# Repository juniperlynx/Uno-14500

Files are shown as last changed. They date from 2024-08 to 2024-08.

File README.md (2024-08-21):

# Uno 14500

The Uno 14500 is a demonstration and training system built around the Motorola MC14500BCP Industrial Control Unit.

Its design borrows heavily from several sources including the Motorola ICU Handbook, Usagi Electric's MC14500 SBC, Nicola Cimmino's PLC14500, and my original Uno computer, a CMOS CPU I wire wrapped in college.

The system has 256 bytes of program memory, an 8 bit scratch register, an 8 bit output register, and an 8 bit input mux.

Program Input is primarily through toggle switches on the front panel, though memory boards with external ROMs are planned for the future. Switch and LED I/O is built into the console, and an external I/O connector is provided to use other peripherals.

I/O and memory mapping is designed to be compatible with either the MCU demonstration system from the Motorola ICU Handbook and the PLC14500 and the mapping of RR into I/O space is jumper selectable on the "Config" header. This header also houses jumpers to enable usage of the JMP and F flags from the CPU for returning to the reset vector and halting the system respectively

This repo, and the system, are still very much works in progress so check back as things are added.

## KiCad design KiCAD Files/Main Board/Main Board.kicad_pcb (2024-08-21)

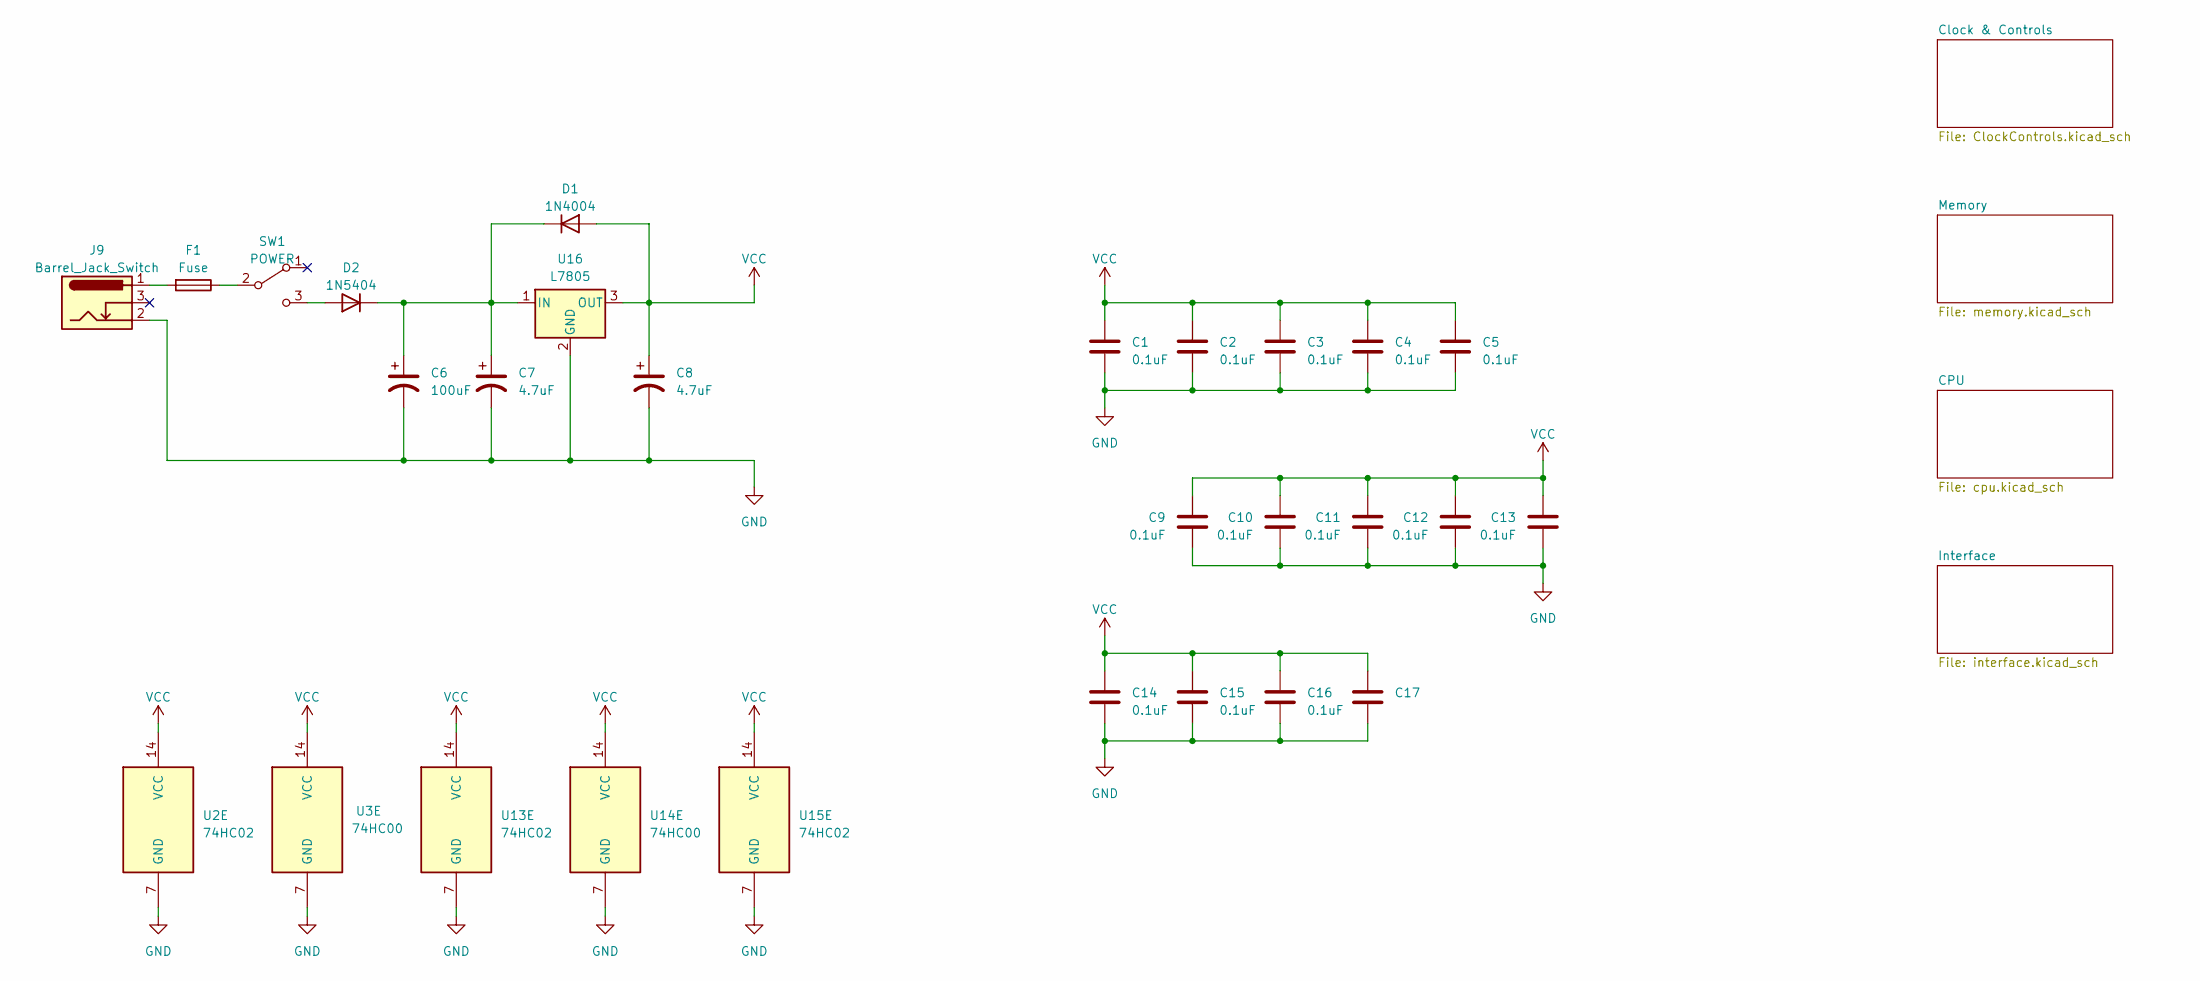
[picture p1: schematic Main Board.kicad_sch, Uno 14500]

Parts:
C1, C2, C3, C4, C5, C9, C10, C11, C12, C13, C14, C15, C16, C17: 0.1uF; C_Axial_L3.8mm_D2.6mm_P10.00mm_Horizontal
C6: 100uF; CP_Radial_D5.0mm_P2.00mm
C7, C8: 4.7uF; C_Rect_L4.6mm_W3.0mm_P2.50mm_MKS02_FKP02
D1: 1N4004; D_DO-41_SOD81_P10.16mm_Horizontal
D2: 1N5404; D_DO-201AE_P15.24mm_Horizontal
F1: Fuse; Fuseholder_Clip-5x20mm_Eaton_1A5601-01_Inline_P20.80x6.76mm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
J9: Barrel_Jack_Switch; BarrelJack_Horizontal
SW1: POWER; SW_SPDT_SW-R3-2B-C-5-13
U2, U13, U15: 74HC02; DIP-14_W7.62mm_Socket_LongPads
U3, U14: 74HC00; DIP-14_W7.62mm_Socket_LongPads
U16: L7805; TO-220-3_Horizontal_TabDown

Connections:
GND: C1.2, C2.2, C3.2, C4.2, C5.2, C6.2, C7.2, C8.2, C9.2, C10.2, C11.2, C12.2, C13.2, C14.2, C15.2, C16.2, C17.2, J9.2, U2.7 (GND), U3.7 (GND), U13.7 (GND), U14.7 (GND), U15.7 (GND), U16.2 (GND); also elsewhere on the board
unnamed: C6.1, C7.1, D1.1 (K), D2.1 (K), U16.1 (IN)
unnamed: D2.2 (A), SW1.3 (C)
unnamed: F1.2, J9.1
unnamed: F1.1, SW1.2 (B)
VCC: C1.1, C2.1, C3.1, C4.1, C5.1, C8.1, C9.1, C10.1, C11.1, C12.1, C13.1, C14.1, C15.1, C16.1, C17.1, D1.2 (A), U2.14 (VCC), U3.14 (VCC), U13.14 (VCC), U14.14 (VCC), U15.14 (VCC), U16.3 (OUT); also elsewhere on the board

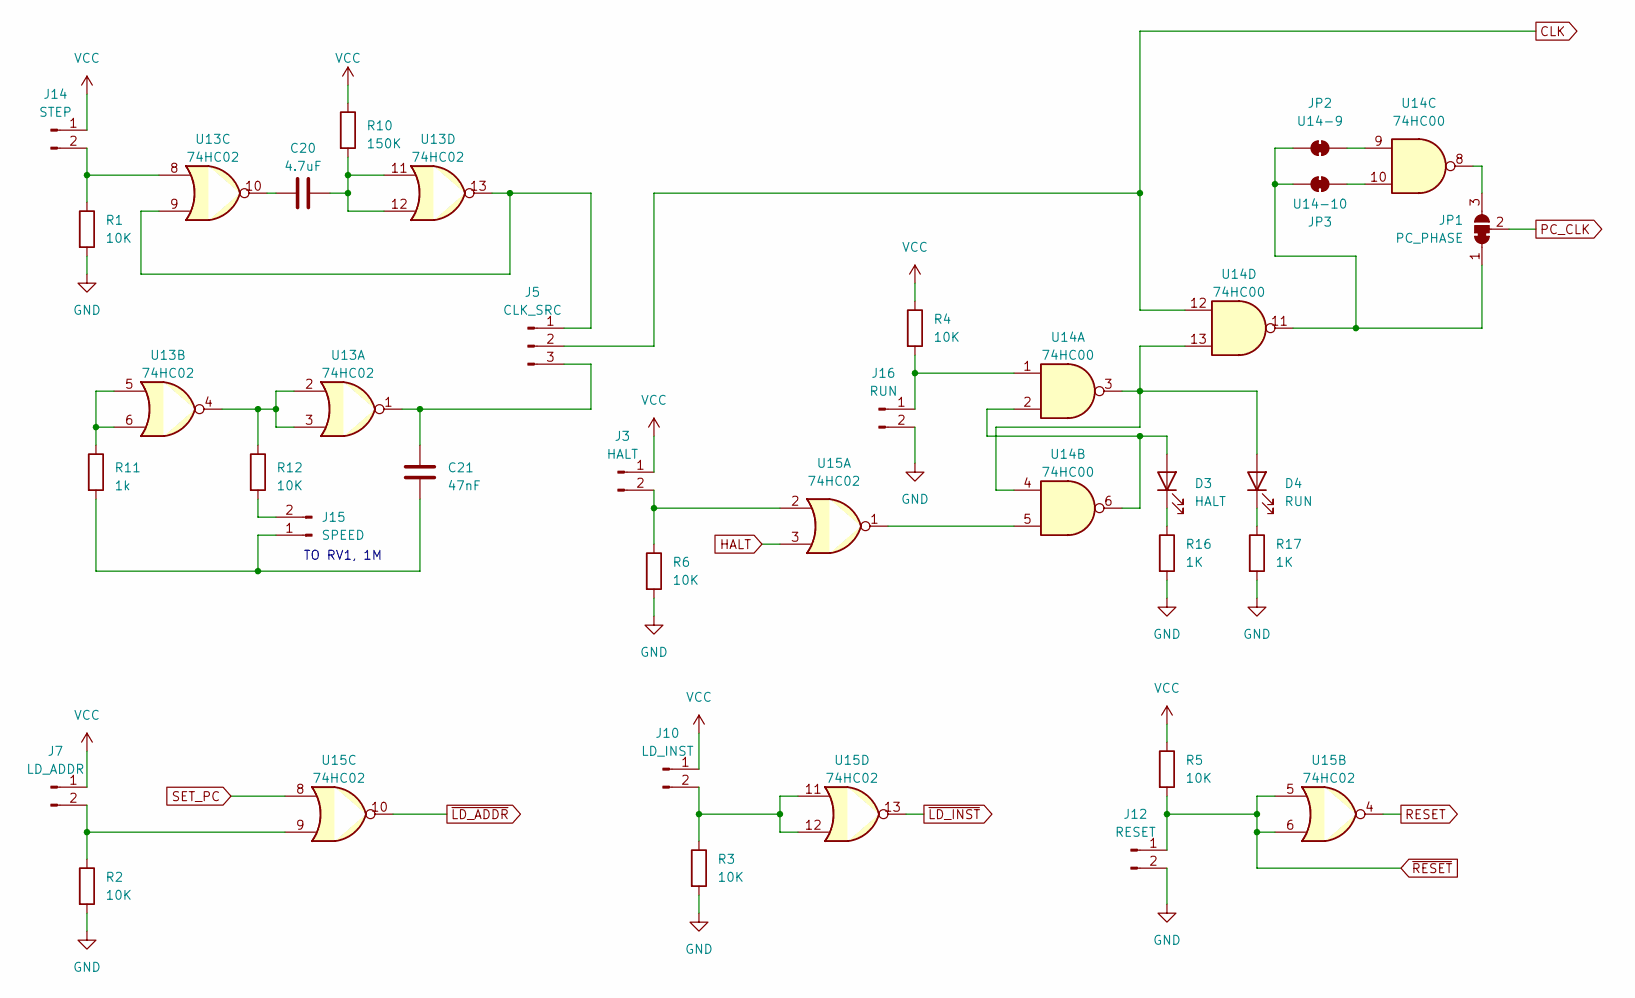
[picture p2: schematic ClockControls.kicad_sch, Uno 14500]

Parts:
C20: 4.7uF; C_Rect_L4.6mm_W3.0mm_P2.50mm_MKS02_FKP02
C21: 47nF; C_Axial_L3.8mm_D2.6mm_P10.00mm_Horizontal
D3: HALT; PinHeader_1x02_P2.54mm_Vertical
D4: RUN; PinHeader_1x02_P2.54mm_Vertical
J3: HALT; PinHeader_1x02_P2.54mm_Vertical
J5: CLK_SRC; PinHeader_1x03_P2.54mm_Vertical
J7: LD_ADDR; PinHeader_1x02_P2.54mm_Vertical
J10: LD_INST; PinHeader_1x02_P2.54mm_Vertical
J12: RESET; PinHeader_1x02_P2.54mm_Vertical
J14: STEP; PinHeader_1x02_P2.54mm_Vertical
J15: SPEED; PinHeader_1x02_P2.54mm_Vertical
J16: RUN; PinHeader_1x02_P2.54mm_Vertical
JP1: PC_PHASE; SolderJumper-3_P1.3mm_Bridged12_RoundedPad1.0x1.5mm
JP2: U14-9; SolderJumper-2_P1.3mm_Bridged_RoundedPad1.0x1.5mm
JP3: U14-10; SolderJumper-2_P1.3mm_Bridged_RoundedPad1.0x1.5mm
R1, R2, R3, R4, R5, R6, R12: 10K; R_Axial_DIN0207_L6.3mm_D2.5mm_P10.16mm_Horizontal
R10: 150K; R_Axial_DIN0207_L6.3mm_D2.5mm_P10.16mm_Horizontal
R11: 1k; R_Axial_DIN0207_L6.3mm_D2.5mm_P10.16mm_Horizontal
R16, R17: 1K; R_Axial_DIN0207_L6.3mm_D2.5mm_P10.16mm_Horizontal
U13, U15: 74HC02; DIP-14_W7.62mm_Socket_LongPads
U14: 74HC00; DIP-14_W7.62mm_Socket_LongPads

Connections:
CLK: J5.2, U14.12; also elsewhere on the board
GND: J12.2, J16.2, R1.2, R2.2, R3.2, R6.2, R16.2, R17.2; also elsewhere on the board
HALT: U15.3; also elsewhere on the board
unnamed: C20.1, U13.10
unnamed: C20.2, R10.2, U13.11, U13.12
unnamed: D3.2 (A), U14.2, U14.6
unnamed: D3.1 (K), R16.1
unnamed: D4.2 (A), U14.3, U14.4, U14.13
unnamed: D4.1 (K), R17.1
unnamed: J3.2, R6.1, U15.2
unnamed: J5.1, U13.9, U13.13
unnamed: C21.1, J5.3, U13.1
unnamed: J7.2, R2.1, U15.9
unnamed: J10.2, R3.1, U15.11, U15.12
unnamed: J14.2, R1.1, U13.8
unnamed: C21.2, J15.1, R11.2
unnamed: J15.2, R12.2
unnamed: J16.1, R4.2, U14.1
unnamed: JP1.1 (A), JP2.1 (A), JP3.2 (B), U14.11
unnamed: JP1.3 (B), U14.8
unnamed: JP2.2 (B), U14.9
unnamed: JP3.1 (A), U14.10
unnamed: R11.1, U13.5, U13.6
unnamed: R12.1, U13.2, U13.3, U13.4
unnamed: U14.5, U15.1
PC_CLK: JP1.2 (C); also elsewhere on the board
RESET: U15.4; also elsewhere on the board
SET_PC: U15.8; also elsewhere on the board
VCC: J3.1, J7.1, J10.1, J14.1, R4.1, R5.1, R10.1; also elsewhere on the board
~LD_ADDR: U15.10; also elsewhere on the board
~LD_INST: U15.13; also elsewhere on the board
~RESET: J12.1, R5.2, U15.5, U15.6; also elsewhere on the board

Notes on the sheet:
TO RV1, 1M

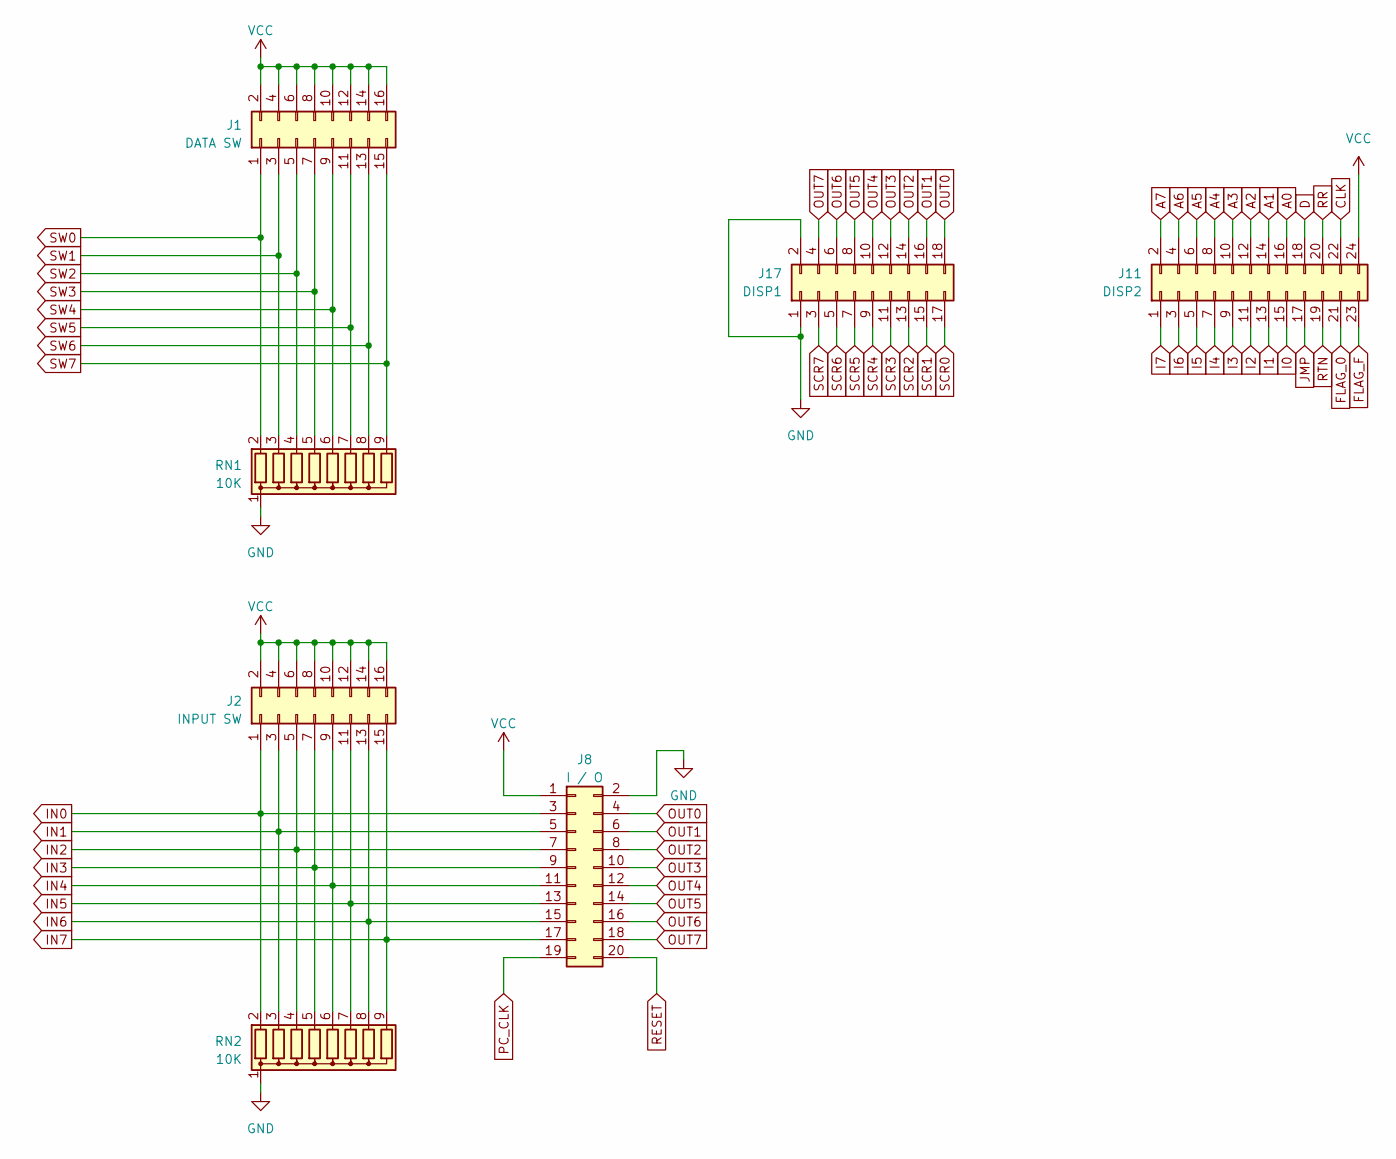
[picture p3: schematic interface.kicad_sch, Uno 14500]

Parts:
J1: DATA SW; PinHeader_2x08_P2.54mm_Vertical
J2: INPUT SW; PinHeader_2x08_P2.54mm_Vertical
J8: I / O; IDC-Header_2x10_P2.54mm_Horizontal
J11: DISP2; IDC-Header_2x12_P2.54mm_Vertical
J17: DISP1; IDC-Header_2x09_P2.54mm_Vertical
RN1, RN2: 10K; R_Array_SIP9

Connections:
A0: J11.16; also elsewhere on the board
A1: J11.14; also elsewhere on the board
A2: J11.12; also elsewhere on the board
A3: J11.10; also elsewhere on the board
A4: J11.8; also elsewhere on the board
A5: J11.6; also elsewhere on the board
A6: J11.4; also elsewhere on the board
A7: J11.2; also elsewhere on the board
CLK: J11.22; also elsewhere on the board
D: J11.18; also elsewhere on the board
FLAG_0: J11.21; also elsewhere on the board
FLAG_F: J11.23; also elsewhere on the board
GND: J8.2, J17.1, J17.2, RN1.1 (common), RN2.1 (common); also elsewhere on the board
I0: J11.15; also elsewhere on the board
I1: J11.13; also elsewhere on the board
I2: J11.11; also elsewhere on the board
I3: J11.9; also elsewhere on the board
I4: J11.7; also elsewhere on the board
I5: J11.5; also elsewhere on the board
I6: J11.3; also elsewhere on the board
I7: J11.1; also elsewhere on the board
IN0: J2.1, J8.3, RN2.2 (R1); also elsewhere on the board
IN1: J2.3, J8.5, RN2.3 (R2); also elsewhere on the board
IN2: J2.5, J8.7, RN2.4 (R3); also elsewhere on the board
IN3: J2.7, J8.9, RN2.5 (R4); also elsewhere on the board
IN4: J2.9, J8.11, RN2.6 (R5); also elsewhere on the board
IN5: J2.11, J8.13, RN2.7 (R6); also elsewhere on the board
IN6: J2.13, J8.15, RN2.8 (R7); also elsewhere on the board
IN7: J2.15, J8.17, RN2.9 (R8); also elsewhere on the board
JMP: J11.17; also elsewhere on the board
OUT0: J8.4, J17.18; also elsewhere on the board
OUT1: J8.6, J17.16; also elsewhere on the board
OUT2: J8.8, J17.14; also elsewhere on the board
OUT3: J8.10, J17.12; also elsewhere on the board
OUT4: J8.12, J17.10; also elsewhere on the board
OUT5: J8.14, J17.8; also elsewhere on the board
OUT6: J8.16, J17.6; also elsewhere on the board
OUT7: J8.18, J17.4; also elsewhere on the board
PC_CLK: J8.19; also elsewhere on the board
RESET: J8.20; also elsewhere on the board
RR: J11.20; also elsewhere on the board
RTN: J11.19; also elsewhere on the board
SCR0: J17.17; also elsewhere on the board
SCR1: J17.15; also elsewhere on the board
SCR2: J17.13; also elsewhere on the board
SCR3: J17.11; also elsewhere on the board
SCR4: J17.9; also elsewhere on the board
SCR5: J17.7; also elsewhere on the board
SCR6: J17.5; also elsewhere on the board
SCR7: J17.3; also elsewhere on the board
SW0: J1.1, RN1.2 (R1); also elsewhere on the board
SW1: J1.3, RN1.3 (R2); also elsewhere on the board
SW2: J1.5, RN1.4 (R3); also elsewhere on the board
SW3: J1.7, RN1.5 (R4); also elsewhere on the board
SW4: J1.9, RN1.6 (R5); also elsewhere on the board
SW5: J1.11, RN1.7 (R6); also elsewhere on the board
SW6: J1.13, RN1.8 (R7); also elsewhere on the board
SW7: J1.15, RN1.9 (R8); also elsewhere on the board
VCC: J1.2, J1.4, J1.6, J1.8, J1.10, J1.12, J1.14, J1.16, J2.2, J2.4, J2.6, J2.8, J2.10, J2.12, J2.14, J2.16, J8.1, J11.24; also elsewhere on the board

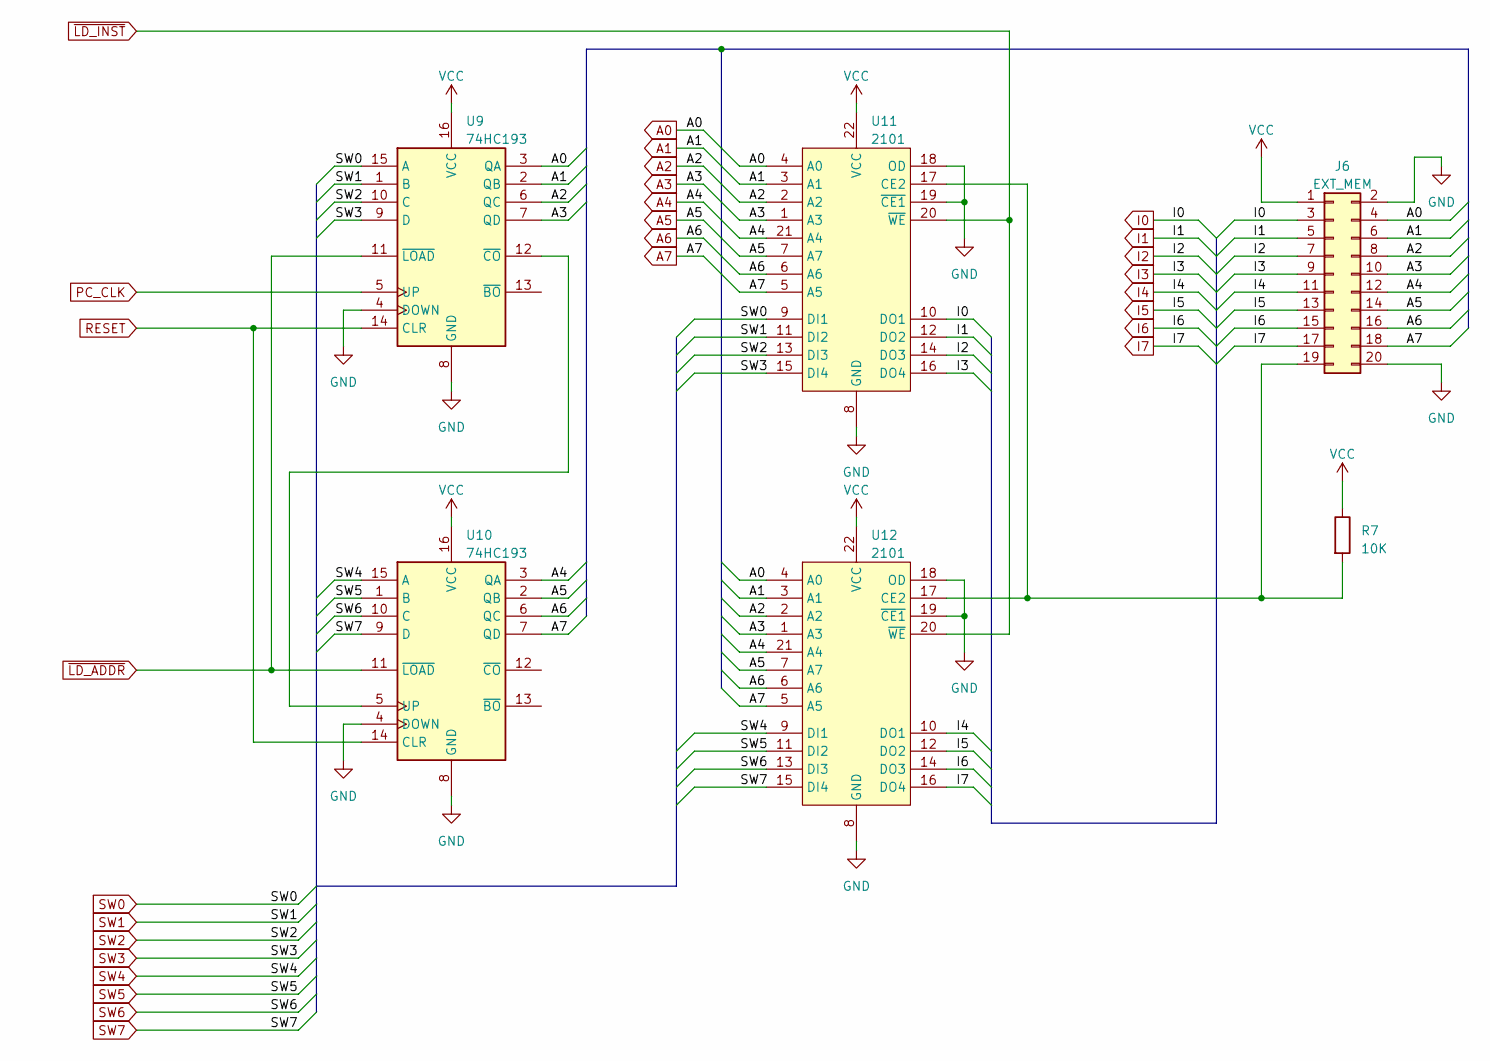
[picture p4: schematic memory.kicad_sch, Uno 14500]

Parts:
J6: EXT_MEM; IDC-Header_2x10_P2.54mm_Horizontal
R7: 10K; R_Axial_DIN0207_L6.3mm_D2.5mm_P10.16mm_Horizontal
U9, U10: 74HC193; DIP-16_W7.62mm_Socket_LongPads
U11, U12: 2101; DIP-22_W10.16mm_Socket_LongPads

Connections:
A0: J6.4, U9.3 (QA), U11.4 (A0), U12.4 (A0); also elsewhere on the board
A1: J6.6, U9.2 (QB), U11.3 (A1), U12.3 (A1); also elsewhere on the board
A2: J6.8, U9.6 (QC), U11.2 (A2), U12.2 (A2); also elsewhere on the board
A3: J6.10, U9.7 (QD), U11.1 (A3), U12.1 (A3); also elsewhere on the board
A4: J6.12, U10.3 (QA), U11.21 (A4), U12.21 (A4); also elsewhere on the board
A5: J6.14, U10.2 (QB), U11.7 (A7), U12.7 (A7); also elsewhere on the board
A6: J6.16, U10.6 (QC), U11.6 (A6), U12.6 (A6); also elsewhere on the board
A7: J6.18, U10.7 (QD), U11.5 (A5), U12.5 (A5); also elsewhere on the board
GND: J6.2, J6.20, U9.4 (DOWN), U9.8 (GND), U10.4 (DOWN), U10.8 (GND), U11.8 (GND), U11.18 (OD), U11.19 (~CE1), U12.8 (GND), U12.18 (OD), U12.19 (~CE1); also elsewhere on the board
I0: J6.3, U11.10 (DO1); also elsewhere on the board
I1: J6.5, U11.12 (DO2); also elsewhere on the board
I2: J6.7, U11.14 (DO3); also elsewhere on the board
I3: J6.9, U11.16 (DO4); also elsewhere on the board
I4: J6.11, U12.10 (DO1); also elsewhere on the board
I5: J6.13, U12.12 (DO2); also elsewhere on the board
I6: J6.15, U12.14 (DO3); also elsewhere on the board
I7: J6.17, U12.16 (DO4); also elsewhere on the board
unnamed: J6.19, R7.2, U11.17 (CE2), U12.17 (CE2)
unnamed: U9.12 (~CO), U10.5 (UP)
PC_CLK: U9.5 (UP); also elsewhere on the board
RESET: U9.14 (CLR), U10.14 (CLR); also elsewhere on the board
SW0: U9.15 (A), U11.9 (DI1); also elsewhere on the board
SW1: U9.1 (B), U11.11 (DI2); also elsewhere on the board
SW2: U9.10 (C), U11.13 (DI3); also elsewhere on the board
SW3: U9.9 (D), U11.15 (DI4); also elsewhere on the board
SW4: U10.15 (A), U12.9 (DI1); also elsewhere on the board
SW5: U10.1 (B), U12.11 (DI2); also elsewhere on the board
SW6: U10.10 (C), U12.13 (DI3); also elsewhere on the board
SW7: U10.9 (D), U12.15 (DI4); also elsewhere on the board
VCC: J6.1, R7.1, U9.16 (VCC), U10.16 (VCC), U11.22 (VCC), U12.22 (VCC); also elsewhere on the board
~LD_ADDR: U9.11 (~LOAD), U10.11 (~LOAD); also elsewhere on the board
~LD_INST: U11.20 (~WE), U12.20 (~WE); also elsewhere on the board

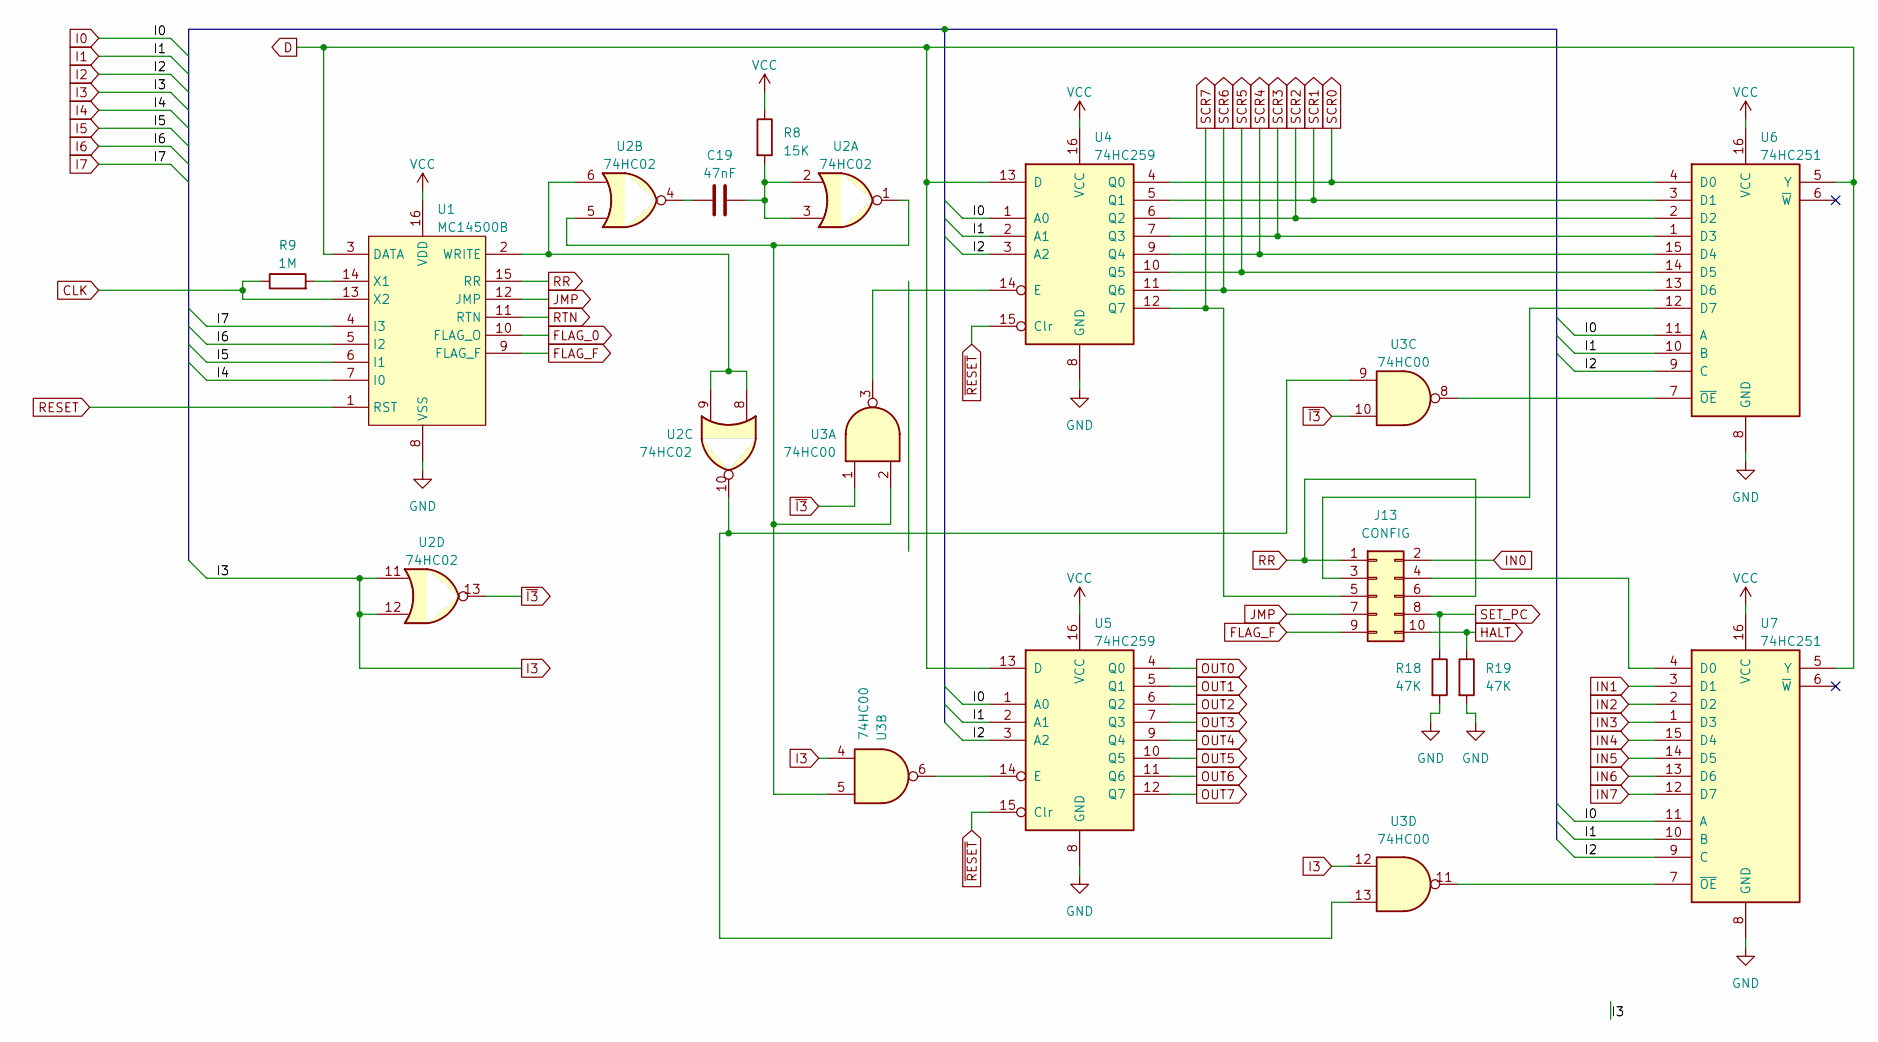
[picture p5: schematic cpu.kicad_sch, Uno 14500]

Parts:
C19: 47nF; C_Axial_L3.8mm_D2.6mm_P10.00mm_Horizontal
J13: CONFIG; IDC-Header_2x05_P2.54mm_Horizontal
R8: 15K; R_Axial_DIN0207_L6.3mm_D2.5mm_P10.16mm_Horizontal
R9: 1M; R_Axial_DIN0207_L6.3mm_D2.5mm_P10.16mm_Horizontal
R18, R19: 47K; R_Axial_DIN0207_L6.3mm_D2.5mm_P10.16mm_Horizontal
U1: MC14500B; DIP-16_W7.62mm_Socket_LongPads
U2: 74HC02; DIP-14_W7.62mm_Socket_LongPads
U3: 74HC00; DIP-14_W7.62mm_Socket_LongPads
U4, U5: 74HC259; DIP-16_W7.62mm_Socket_LongPads
U6, U7: 74HC251; DIP-16_W7.62mm_Socket_LongPads

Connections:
CLK: R9.1, U1.13 (X2); also elsewhere on the board
D: U1.3 (DATA), U4.13 (D), U5.13 (D), U6.5 (Y), U7.5 (Y); also elsewhere on the board
FLAG_0: U1.10 (FLAG_O); also elsewhere on the board
FLAG_F: J13.9, U1.9 (FLAG_F); also elsewhere on the board
GND: R18.2, R19.2, U1.8 (VSS), U4.8 (GND), U5.8 (GND), U6.8 (GND), U7.8 (GND); also elsewhere on the board
HALT: J13.10, R19.1; also elsewhere on the board
I0: U4.1 (A0), U5.1 (A0), U6.11 (A), U7.11 (A); also elsewhere on the board
I1: U4.2 (A1), U5.2 (A1), U6.10 (B), U7.10 (B); also elsewhere on the board
I2: U4.3 (A2), U5.3 (A2), U6.9 (C), U7.9 (C); also elsewhere on the board
I3: U2.11, U2.12, U3.4, U3.12; also elsewhere on the board
I4: U1.7 (I0); also elsewhere on the board
I5: U1.6 (I1); also elsewhere on the board
I6: U1.5 (I2); also elsewhere on the board
I7: U1.4 (I3); also elsewhere on the board
IN0: J13.2; also elsewhere on the board
IN1: U7.3 (D1); also elsewhere on the board
IN2: U7.2 (D2); also elsewhere on the board
IN3: U7.1 (D3); also elsewhere on the board
IN4: U7.15 (D4); also elsewhere on the board
IN5: U7.14 (D5); also elsewhere on the board
IN6: U7.13 (D6); also elsewhere on the board
IN7: U7.12 (D7); also elsewhere on the board
JMP: J13.7, U1.12 (JMP); also elsewhere on the board
unnamed: C19.1, U2.4
unnamed: C19.2, R8.2, U2.2, U2.3
unnamed: J13.3, U6.12 (D7)
unnamed: J13.4, U7.4 (D0)
unnamed: U1.2 (WRITE), U2.6, U2.8, U2.9
unnamed: R9.2, U1.14 (X1)
unnamed: U2.1, U2.5, U3.2, U3.5
unnamed: U2.10, U3.9, U3.13
unnamed: U3.3, U4.14 (E)
unnamed: U3.6, U5.14 (E)
unnamed: U3.8, U6.7 (~OE)
unnamed: U3.11, U7.7 (~OE)
OUT0: U5.4 (Q0); also elsewhere on the board
OUT1: U5.5 (Q1); also elsewhere on the board
OUT2: U5.6 (Q2); also elsewhere on the board
OUT3: U5.7 (Q3); also elsewhere on the board
OUT4: U5.9 (Q4); also elsewhere on the board
OUT5: U5.10 (Q5); also elsewhere on the board
OUT6: U5.11 (Q6); also elsewhere on the board
OUT7: U5.12 (Q7); also elsewhere on the board
RESET: U1.1 (RST); also elsewhere on the board
RR: J13.1, J13.6, U1.15 (RR); also elsewhere on the board
RTN: U1.11 (RTN); also elsewhere on the board
SCR0: U4.4 (Q0), U6.4 (D0); also elsewhere on the board
SCR1: U4.5 (Q1), U6.3 (D1); also elsewhere on the board
SCR2: U4.6 (Q2), U6.2 (D2); also elsewhere on the board
SCR3: U4.7 (Q3), U6.1 (D3); also elsewhere on the board
SCR4: U4.9 (Q4), U6.15 (D4); also elsewhere on the board
SCR5: U4.10 (Q5), U6.14 (D5); also elsewhere on the board
SCR6: U4.11 (Q6), U6.13 (D6); also elsewhere on the board
SCR7: J13.5, U4.12 (Q7); also elsewhere on the board
SET_PC: J13.8, R18.1; also elsewhere on the board
VCC: R8.1, U1.16 (VDD), U4.16 (VCC), U5.16 (VCC), U6.16 (VCC), U7.16 (VCC); also elsewhere on the board
~I3: U2.13, U3.1, U3.10
~RESET: U4.15 (Clr), U5.15 (Clr); also elsewhere on the board

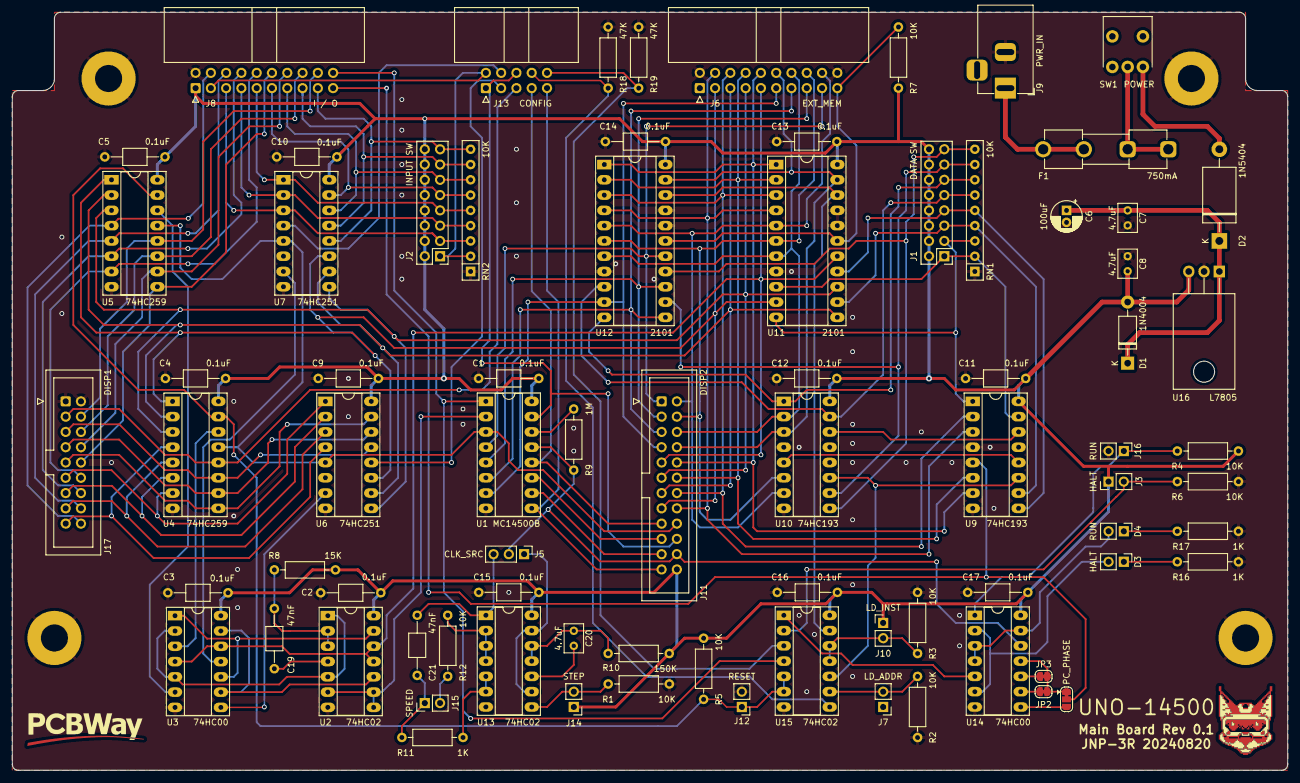
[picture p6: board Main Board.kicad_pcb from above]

Board: 2 copper layers, 212.0 x 126.0 mm, 78 parts (0 on the bottom side), 105 nets.

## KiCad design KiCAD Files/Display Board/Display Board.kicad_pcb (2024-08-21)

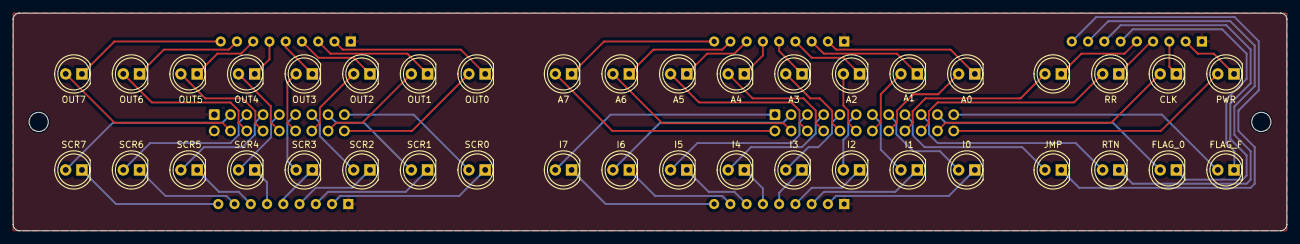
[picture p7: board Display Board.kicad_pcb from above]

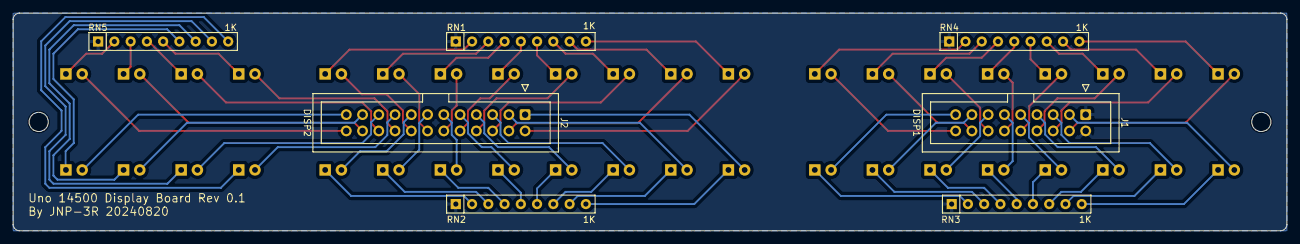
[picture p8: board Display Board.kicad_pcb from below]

Board: 2 copper layers, 199.0 x 34.0 mm, 47 parts (7 on the bottom side), 81 nets.

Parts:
D1: A0; LED_D5.0mm
D2: A1; LED_D5.0mm
D3: A2; LED_D5.0mm
D4: A3; LED_D5.0mm
D5: A4; LED_D5.0mm
D6: A5; LED_D5.0mm
D7: A6; LED_D5.0mm
D8: A7; LED_D5.0mm
D9: I0; LED_D5.0mm
D10: I1; LED_D5.0mm
D11: I2; LED_D5.0mm
D12: I3; LED_D5.0mm
D13: I4; LED_D5.0mm
D14: I5; LED_D5.0mm
D15: I6; LED_D5.0mm
D16: I7; LED_D5.0mm
D17: SCR0; LED_D5.0mm
D18: SCR1; LED_D5.0mm
D19: SCR2; LED_D5.0mm
D20: SCR3; LED_D5.0mm
D21: SCR4; LED_D5.0mm
D22: SCR5; LED_D5.0mm
D23: SCR6; LED_D5.0mm
D24: SCR7; LED_D5.0mm
D25: OUT0; LED_D5.0mm
D26: OUT1; LED_D5.0mm
D27: OUT2; LED_D5.0mm
D28: OUT3; LED_D5.0mm
D29: OUT4; LED_D5.0mm
D30: OUT5; LED_D5.0mm
D31: OUT6; LED_D5.0mm
D32: OUT7; LED_D5.0mm
D33: PWR; LED_D5.0mm
D34: CLK; LED_D5.0mm
D35: RR; LED_D5.0mm
D36: D; LED_D5.0mm
D37: FLAG_F; LED_D5.0mm
D38: FLAG_0; LED_D5.0mm
D39: RTN; LED_D5.0mm
D40: JMP; LED_D5.0mm
J1: DISP1; IDC-Header_2x09_P2.54mm_Vertical
J2: DISP2; IDC-Header_2x12_P2.54mm_Vertical
RN1, RN2, RN3, RN4, RN5: 1K; R_Array_SIP9

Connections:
A0: D1.2 (A), J2.16
A1: D2.2 (A), J2.14
A2: D3.2 (A), J2.12
A3: D4.2 (A), J2.10
A4: D5.2 (A), J2.8
A5: D6.2 (A), J2.6
A6: D7.2 (A), J2.4
A7: D8.2 (A), J2.2
CLK: D34.2 (A), J2.22
D: D36.2 (A), J2.18
FLAG_0: D38.2 (A), J2.21
FLAG_F: D37.2 (A), J2.23
GND: J1.1, J1.2, RN1.1 (R1.1), RN2.1 (R1.1), RN3.1 (R1.1), RN4.1 (R1.1), RN5.1 (R1.1)
I0: D9.2 (A), J2.15
I1: D10.2 (A), J2.13
I2: D11.2 (A), J2.11
I3: D12.2 (A), J2.9
I4: D13.2 (A), J2.7
I5: D14.2 (A), J2.5
I6: D15.2 (A), J2.3
I7: D16.2 (A), J2.1
JMP: D40.2 (A), J2.17
unnamed: D1.1 (K), RN1.2 (R1.2)
unnamed: D2.1 (K), RN1.3 (R2.2)
unnamed: D3.1 (K), RN1.4 (R3.2)
unnamed: D4.1 (K), RN1.5 (R4.2)
unnamed: D5.1 (K), RN1.6 (R5.2)
unnamed: D6.1 (K), RN1.7 (R6.2)
unnamed: D7.1 (K), RN1.8 (R7.2)
unnamed: D8.1 (K), RN1.9 (R8.2)
unnamed: D9.1 (K), RN2.2 (R1.2)
unnamed: D10.1 (K), RN2.3 (R2.2)
unnamed: D11.1 (K), RN2.4 (R3.2)
unnamed: D12.1 (K), RN2.5 (R4.2)
unnamed: D13.1 (K), RN2.6 (R5.2)
unnamed: D14.1 (K), RN2.7 (R6.2)
unnamed: D15.1 (K), RN2.8 (R7.2)
unnamed: D16.1 (K), RN2.9 (R8.2)
unnamed: D17.1 (K), RN3.2 (R1.2)
unnamed: D18.1 (K), RN3.3 (R2.2)
unnamed: D19.1 (K), RN3.4 (R3.2)
unnamed: D20.1 (K), RN3.5 (R4.2)
unnamed: D21.1 (K), RN3.6 (R5.2)
unnamed: D22.1 (K), RN3.7 (R6.2)
unnamed: D23.1 (K), RN3.8 (R7.2)
unnamed: D24.1 (K), RN3.9 (R8.2)
unnamed: D25.1 (K), RN4.2 (R1.2)
unnamed: D26.1 (K), RN4.3 (R2.2)
unnamed: D27.1 (K), RN4.4 (R3.2)
unnamed: D28.1 (K), RN4.5 (R4.2)
unnamed: D29.1 (K), RN4.6 (R5.2)
unnamed: D30.1 (K), RN4.7 (R6.2)
unnamed: D31.1 (K), RN4.8 (R7.2)
unnamed: D32.1 (K), RN4.9 (R8.2)
unnamed: D33.1 (K), RN5.2 (R1.2)
unnamed: D34.1 (K), RN5.3 (R2.2)
unnamed: D35.1 (K), RN5.4 (R3.2)
unnamed: D36.1 (K), RN5.5 (R4.2)
unnamed: D37.1 (K), RN5.6 (R5.2)
unnamed: D38.1 (K), RN5.7 (R6.2)
unnamed: D39.1 (K), RN5.8 (R7.2)
unnamed: D40.1 (K), RN5.9 (R8.2)
OUT0: D25.2 (A), J1.18
OUT1: D26.2 (A), J1.16
OUT2: D27.2 (A), J1.14
OUT3: D28.2 (A), J1.12
OUT4: D29.2 (A), J1.10
OUT5: D30.2 (A), J1.8
OUT6: D31.2 (A), J1.6
OUT7: D32.2 (A), J1.4
RR: D35.2 (A), J2.20
RTN: D39.2 (A), J2.19
SCR0: D17.2 (A), J1.17
SCR1: D18.2 (A), J1.15
SCR2: D19.2 (A), J1.13
SCR3: D20.2 (A), J1.11
SCR4: D21.2 (A), J1.9
SCR5: D22.2 (A), J1.7
SCR6: D23.2 (A), J1.5
SCR7: D24.2 (A), J1.3
VCC: D33.2 (A), J2.24

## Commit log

2024-08-21 Initial Commit
    Initial commit of Rev 0.1 Files
    [ClockControls.kicad_sch, Display Board.kicad_pcb, Display Board.kicad_sch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]
2024-08-26 Add Front Panel schematic
    Add schematic to front panel project. PCB is still mechanical only, but handwiring is now documented.
    [Front Panel.kicad_sch]
